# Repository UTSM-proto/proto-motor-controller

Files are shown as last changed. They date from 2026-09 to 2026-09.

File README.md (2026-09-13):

# UTSM motor controller

RP2040 Pico firmware and StinkyController KiCad hardware.

On Windows, double-click **Launch Programmer.cmd** to edit the firmware configuration and build/program a connected Pico. The editor includes 40 settings plus the manual hall table, descriptions, sliders, numeric inputs, voltage conversion, profile import/export and a build log.

See [programmer setup and operation](programmer/README.md) for dependencies, firmware changes and testing. See [hardware files](hardware/StinkyController/README.md) for PCB revisions and manufacturing outputs. `blink.c` is the active firmware target; `temp.c` is a legacy copy and is not built.

The GUI generates an isolated configuration header for each build. The checked-in firmware defaults are in `firmware/controller_config.h`; `programmer/config.py` defines the editor schema and validation. Keep both synchronized when changing defaults.

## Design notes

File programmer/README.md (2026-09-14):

# Windows Pico programmer

Double-click **Launch Programmer.cmd** in the repository root. Python starts a local service and opens the configuration page in your browser. Keep its terminal open while using the app. Python 3.10+ is required; the app itself has no pip dependencies.

1. Adjust settings using number fields, sliders or On/Off menus. Throttle thresholds also accept external volts; the default 5 V display scale corresponds to 4095 ADC counts, not permission to apply 5 V to a Pico pin.
2. Save/import JSON profiles to keep configurations. Defaults match the last 1.25 V throttle setting, with synchronous switching off. The sensor scale factors now retain the fractional part that the old integer constants discarded.
3. Connect a Pico normally by USB. Detection updates automatically every ten seconds; **Refresh devices** also checks immediately. Select the Pico if more than one is connected.
4. **Build UF2 only** compiles without touching hardware. **Build & program Pico** builds a snapshot, requests a software USB reboot, follows the selected physical USB port into the bootloader, and transfers the UF2 through Windows' standard USB drive interface. It then waits for the application to return on that port and report the expected build ID. No manual BOOTSEL step or RP2 Boot WinUSB driver is required in normal operation. Automatic identification moves the motor on restart. Release throttle before operation.
5. Close other serial monitors before programming. Software reboot requires responsive firmware with Pico SDK USB reset support. If firmware hangs or USB is disabled, manual BOOTSEL remains the recovery method. Devices using nonstandard USB IDs are not currently enumerated. Only the original RP2040 Pico is supported by this build target.

The application and bootloader may have different serial numbers. The programmer correlates their physical USB location and resolves the bootloader volume through Windows device ancestry, never just by drive letter or volume label. Completion requires the expected firmware build ID over USB after transfer; this is startup confirmation, not byte-for-byte flash readback or validation of motor behavior. The [Pico SDK USB reset mechanism](https://github.com/raspberrypi/pico-sdk/blob/2.1.0/src/rp2_common/pico_stdio_usb/reset_interface.c) uses a 1200-baud serial request. Picotool remains a build dependency for producing UF2 files, but is not used to upload them.

Every build lives in `.programmer/builds/<id>/`, with `config.json`, the source snapshot, `controller.uf2`, `manifest.json` (including SHA-256), and `operation.log`. Download UF2 from the page or use the saved file. Builds do not modify the checked-in default header. Changes made while a build runs belong to the next build.

Matching builds are reused automatically for both build-only and programming operations. The cache key covers the generated configuration, firmware sources, build recipe, executable checksums, SDK/toolchain file sizes and modification times, and relevant build environment. Each cache hit verifies the UF2 checksum and keeps the original firmware build ID for USB startup confirmation. Missing or damaged cache files cause a rebuild. Cache entries are saved after successful compilation even if the subsequent USB operation fails, so a programming retry does not compile again. Builds made before the cache was introduced require one new build to establish their cache entry. Each operation still gets its own log and manifest.

The launcher uses one dashboard on port 8766. Launching it again opens the existing instance; after an update it gracefully replaces an idle outdated instance. A running build/write cannot be interrupted this way. An old server also refuses new programming jobs if its backend files have changed, with a message to run the launcher again.

## Serial monitor and motor diagnosis

Select the connected Pico and use **Connect monitor**. The monitor reads USB at 115200 baud, shows raw timestamped lines and decoded calibration, drive-block, throttle ADC, hall, motor-state and duty/armed values. It can read the older CSV format too. Connecting does not reboot the Pico or send motor commands. **Clear display** clears the browser buffer; **Save visible log** exports it. Up to 1500 lines are retained for display, and each connection saves up to 10 MB under `.programmer/serial/`.

If the monitor is connected when programming begins, the programmer closes its serial handle before USB reset and reconnects after successful firmware confirmation. Disconnect any external serial monitor to avoid port conflicts. A failed upload may leave this monitor paused; reconnect it when the device is back in normal USB mode.

Firmware diagnostics persist after startup: `cal` reports success or the calibration failure type, `cal_sector` identifies the failed sector, and `cal_observed` lists the six sampled hall codes (255 means unavailable/rejected). `raw_hall` is the last simultaneous GPIO snapshot; binary digits are Hall C, B, A. `hall` is the majority-filtered code. `block` explains why drive is disabled. `throttle_not_released` means the throttle has not gone below the start threshold since boot; `calibration_failed` means PWM control was never enabled. These diagnostic additions do not alter calibration passes or relax validation.

Start diagnosis with the persistent calibration result. If calibration failed, inspect the recorded sector/codes before changing duty, settling time or pass count. If calibration passed, inspect throttle ADC/arming, then hall transition counters and commanded duty. Firmware startup confirmation during upload does not imply calibration passed or motor drive is ready.

Brief ambiguous Hall reads now blank the outputs without resetting the throttle ramp. The `invalid` counter includes whole-state vote ties, not only physical 000/111 inputs. `duty` reports the retained internal command; outputs are off whenever `block=invalid_hall` or `hall_settling`. The current integrator is frozen while blanked. If no stable sector is accepted for `HALL_LOSS_TIMEOUT_CYCLES` (default 16, approximately 1 ms at 16 kHz), `block=hall_loss_fault` latches drive off and resets the ramp until throttle release. Skipped-sector and ADC shutdowns remain in place. The timeout must exceed runtime stable cycles. This recovery timing still needs physical bench acceptance.

Profiles saved before the Hall loss timeout setting was added must be recreated using the current editor; older schemas are rejected explicitly. Reload the dashboard using the launcher after updating the backend.

## Build tools

The page reports detected tool paths. It supports the Pico VS Code tool layout, the existing UTSM tools directory, STM32Cube Arm GCC/Ninja, or explicit environment variables:

| Variable | Value |
| --- | --- |
| `PICO_SDK_PATH` | Pico SDK 2.1.0 directory, including the TinyUSB submodule |
| `UTSM_CMAKE` | Full path to `cmake.exe` |
| `UTSM_NINJA` | Full path to `ninja.exe` |
| `UTSM_ARM_GCC` | Full path to `arm-none-eabi-gcc.exe` |
| `UTSM_PICOTOOL` | Full path to `picotool.exe`; keep its CMake package files alongside it |

Install Python, Git, CMake, Ninja, the Arm GNU embedded toolchain and [picotool](https://github.com/raspberrypi/picotool/releases). The tested laptop uses SDK 2.1.0, Arm GCC 14.3.1 and picotool 2.3.1. To install the SDK into the auto-detected directory from PowerShell:

```powershell
git clone --depth 1 --branch 2.1.0 https://github.com/raspberrypi/pico-sdk.git "$env:LOCALAPPDATA\UTSM\PicoTools\pico-sdk-2.1.0"
git -C "$env:LOCALAPPDATA\UTSM\PicoTools\pico-sdk-2.1.0" submodule update --init --depth 1 lib/tinyusb
```

Do not run the clone command over an existing SDK checkout. Restart the programmer after changing environment variables. On another laptop, missing tools block the build with an actionable error; the app does not silently install software.

## Firmware fixes in this branch

- Startup hall identification runs once. It gathers consecutive stable whole-state readings, rejects invalid/duplicate states, and publishes a table only after all six sectors pass. Failed identification or a bad manual table keeps the drive disabled.
- Hall inputs use one GPIO register snapshot per sample and vote on complete three-bit codes. Temporal filtering spans PWM cycles. Uncertain states blank the phases; normal settling does not reset the throttle ramp. Skipped-sector faults clear when throttle is released, allowing resynchronization without reboot.
- Three ordered blocking ADC conversions replace the FIFO race. They read explicitly selected current, bus-voltage and throttle channels. ADC errors turn drive off and require throttle release. The control-loop timing must still be measured on hardware, especially with current control enabled.
- PWM outputs receive their off levels after initialization and before the GPIO function is switched. This avoids initialization clearing the off compare value on inverted low-side outputs.
- Current control handles zero duty without division by zero, uses a wide intermediate for current-limit arithmetic, and cannot integrate positive duty at zero throttle.
- Synchronous switching is one explicit setting, off by default in both control modes. The GUI validates pin uniqueness, paired PWM channels, separate slices, ADC pins, throttle ordering and manual tables.
- Telemetry snapshots shared values before printing: `current_mA,target_mA,duty16,bus_mV,hall,motor_state,invalid=N,transitions=N,adc=N`. Each interval also prints `build=<id>` for programming confirmation. A hall value of 255 means the sampled state was rejected. Calibration/table failures print a fault repeatedly.

The PCB's 5 V hall pull-ups remain a hardware issue. These firmware fixes cannot level-shift the hall inputs. Inspect the interface before powered tests. Calibration can still fail if duty is too low to move the rotor; it will now report failure and disable drive instead of accepting an incomplete table.

## Verification and bench acceptance

```powershell
python -m unittest discover -s tests -v
gcc -std=c11 -Wall -Wextra -Werror tests\test_logic.c -o .programmer\test_logic.exe
.\.programmer\test_logic.exe
```

`gcc` in this test command is a Windows host compiler, not Arm GCC. Create `.programmer` first if the app has never run. `tests/browser_smoke.cjs` additionally exercises the actual page and build using Playwright; set `PROGRAMMER_URL` to the authenticated URL printed by the service.

Before accepting motor operation, verify the gate outputs and ISR timing with a scope, confirm hall pin voltages, capture a complete calibration table, and check slow forward/reverse hand rotation with the power stage disabled. Then test controlled low-power startup, zero-throttle shutoff and hall-fault recovery. A successful build or USB verification does not establish correct motor commutation.

The service listens only on 127.0.0.1 and uses a random session token plus host/origin checks. There is no remote control endpoint, shell input, or automatic flash on page load.

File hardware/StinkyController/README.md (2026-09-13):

# StinkyController hardware

This directory contains the KiCad PCB projects and manufacturing outputs from
the supplied `StinkyController 0.5.zip` archive.

## Project revisions

- `StinkyController 0.5`
- `StinkyController 1`
- `StinkyController 1.1`
- `StinkyController MK2` (newest PCB and Gerber revision in the archive)

The `gerb*` directories and ZIP files contain the supplied manufacturing
outputs. Generated KiCad user preferences, caches, backups, and macOS metadata
are excluded from version control.

## Missing source

The supplied archive does not contain a `.kicad_sch` schematic file. The PCB
files retain component values, footprints, net names, and routed connectivity,
but the editable schematic source will need to be added separately if it still
exists.

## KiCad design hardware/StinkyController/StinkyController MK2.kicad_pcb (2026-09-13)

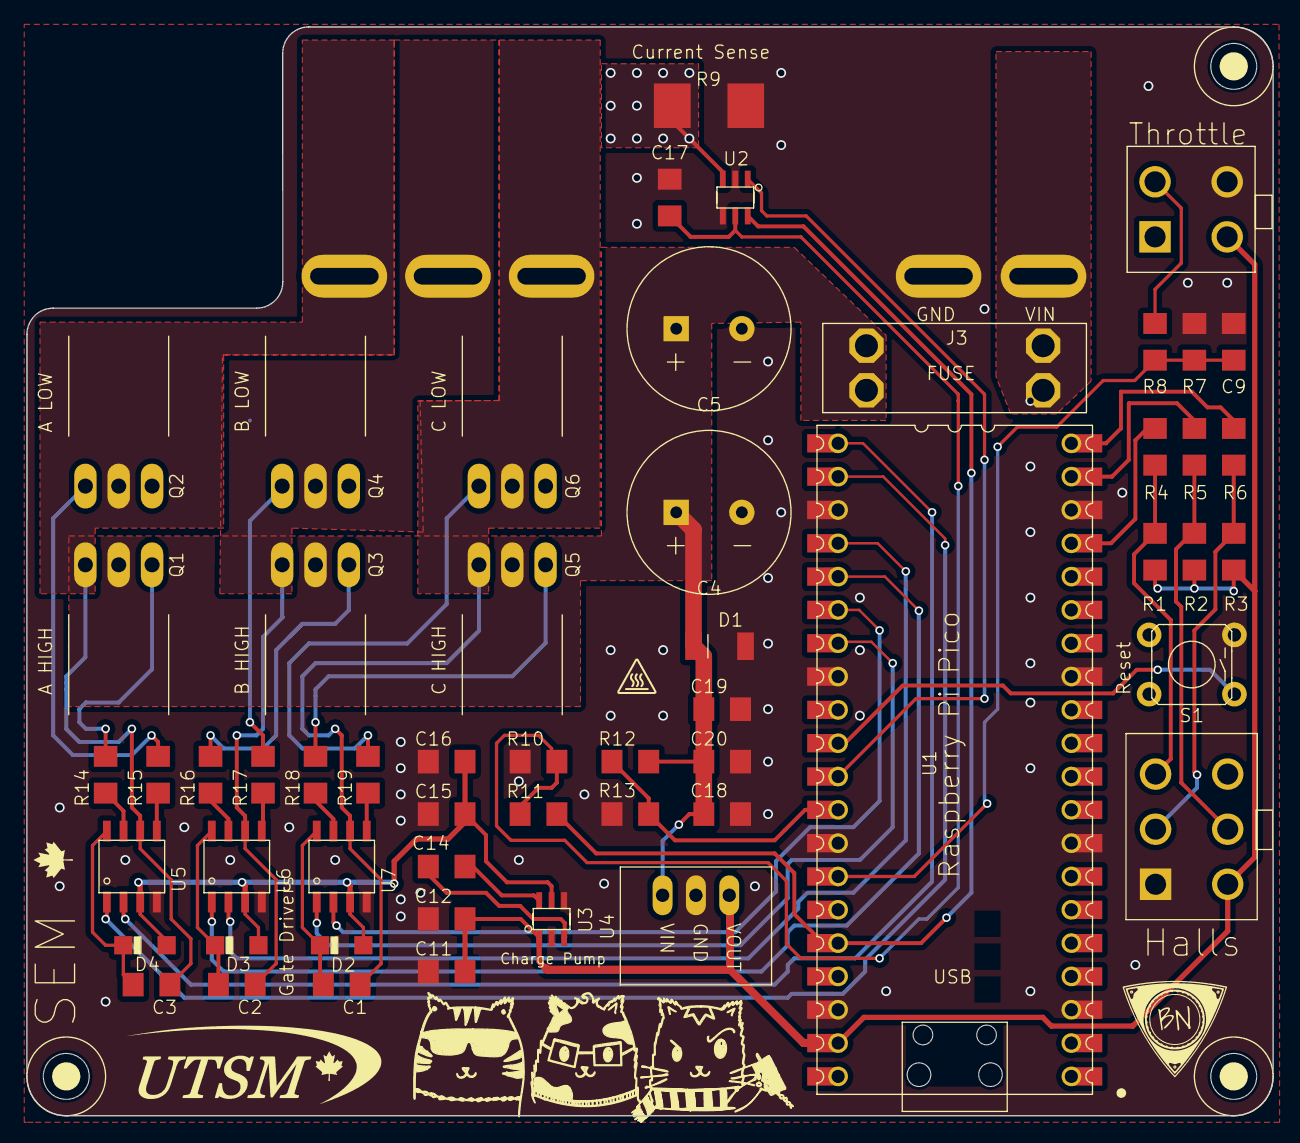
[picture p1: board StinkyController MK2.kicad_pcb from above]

Board: 2 copper layers, 95.0 x 83.0 mm, 58 parts (0 on the bottom side), 46 nets.

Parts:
C1, C2, C3, C11, C12, C14, C15, C16, C17, C18, C19, C20: 1uF; 1206
C4, C5: 470uF; CPOL-RADIAL-5MM-10MM
C9: 22nF; 1206
D1: TVS; DO-214AC
D2, D3, D4: SOD-123
J1: HEADER4VALULOK; 4PINVALULOK
J2: HEADER6; 6PINVALULOK
J3: FUSE; AUTO_FUSE
Q1, Q2, Q3, Q4, Q5, Q6: TO-220-FLAT
R1, R2, R3, R4, R5, R6, R13: 2.2k; 1206
R7, R8, R10, R11, R12: 47k; 1206
R9: 0.0005; R2512
R14, R15, R16, R17, R18, R19: 22; 1206
S1: TACTILE_SWITCH_PTH_6.0MM
U1: PICO-PKG-NO_DEBUG
U2: INA181; SOT23-6
U3: TC1240A; SOT23-6
U4: K78U05; V78W_BACKWARDS
U5, U6, U7: DGD2304; SOIC8
U$10, U$11, U$12: SCREW; M3HOLE

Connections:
3.3V: R11.2, U1.36, U1.P$36, U2.6
5V: C11.1, C12.1, J1.2, J2.2, R1.2, R2.2, R3.2, U1.39, U1.P$39, U3.1, U4.OUT
10V: C15.1, C16.1, D2.+, D3.+, D4.+, U3.5, U5.3, U6.3, U7.3
COM_A: C3.2, Q1.3, Q2.2, U5.6
COM_B: C2.2, Q3.3, Q4.2, U6.6
COM_C: C1.2, Q5.3, Q6.2, U7.6
CTRL_AH: U1.21, U1.P$21, U5.2
CTRL_AL: U1.22, U1.P$22, U5.1
CTRL_BH: U1.24, U1.P$24, U6.2
CTRL_BL: U1.25, U1.P$25, U6.1
CTRL_CH: U1.26, U1.P$26, U7.2
CTRL_CL: U1.27, U1.P$27, U7.1
DRV_AH: R14.1, U5.7
DRV_AL: R15.1, U5.5
DRV_BH: R16.1, U6.7
DRV_BL: R17.1, U6.5
DRV_CH: R18.1, U7.7
DRV_CL: R19.1, U7.5
GND: C4.-, C5.-, C9.2, C11.2, C12.2, C15.2, C16.2, C17.2, C18.2, C19.2, C20.2, D1.A, J1.4, J2.1, R7.1, R9.1, R10.1, R13.1, S1.3, U1.3, U1.8, U1.13, U1.18, U1.23, U1.28, U1.33, U1.38, U1.P$3, U1.P$8, U1.P$13, U1.P$18, U1.P$23, U1.P$28, U1.P$33, U1.P$38, U2.2, U2.4, U3.2, U3.4, U4.GND, U5.4, U6.4, U7.4
HALL_A: R4.2, U1.17, U1.P$17
HALL_B: R5.2, U1.19, U1.P$19
HALL_C: R6.2, U1.20, U1.P$20
ISENSE: U1.31, U1.P$31, U2.1
unnamed: C2.1, D3.-, U6.8
unnamed: J2.3, R3.1, R6.1
unnamed: C3.1, D4.-, U5.8
unnamed: J2.4, R2.1, R5.1
unnamed: Q1.1, R14.2
unnamed: J2.5, R1.1, R4.1
unnamed: J1.3, R8.1
unnamed: C1.1, D2.-, U7.8
unnamed: S1.1, U1.30, U1.P$30
unnamed: C17.1, R10.2, R11.1, U2.5
unnamed: Q2.1, R15.2
unnamed: Q3.1, R16.2
unnamed: Q4.1, R17.2
unnamed: Q5.1, R18.2
unnamed: Q6.1, R19.2
unnamed: C14.1, U3.3
unnamed: C14.2, U3.6
SHUNT+: Q2.3, Q4.3, Q6.3, R9.2, U2.3
THROTTLE: C9.1, R7.2, R8.2, U1.34, U1.P$34
VBUS: U1.40, U1.P$40
VSENSE: R12.1, R13.2, U1.32, U1.P$32
V_PREFUSE: J3.1A, J3.1B
V_RAW: C4.+, C5.+, C18.1, C19.1, C20.1, D1.C, J3.2A, J3.2B, Q1.2, Q3.2, Q5.2, R12.2, U4.IN

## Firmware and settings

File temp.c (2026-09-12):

#include <stdio.h>

#include "hardware/adc.h"
#include "hardware/clocks.h"
#include "hardware/gpio.h"
#include "hardware/irq.h"
#include "hardware/pwm.h"
#include "hardware/sync.h"
#include "hardware/uart.h"
#include "pico/stdlib.h"

///////

/**
 * Copyright (c) 2020 Raspberry Pi (Trading) Ltd.
 *
 * SPDX-License-Identifier: BSD-3-Clause
 */

#include "pico/stdlib.h"
// Pico W devices use a GPIO on the WIFI chip for the LED,
// so when building for Pico W, CYW43_WL_GPIO_LED_PIN will be defined
#ifdef CYW43_WL_GPIO_LED_PIN
#include "pico/cyw43_arch.h"
#endif

#ifndef LED_DELAY_MS
#define LED_DELAY_MS 100
#endif

// Perform initialisation
int pico_led_init(void) {
#if defined(PICO_DEFAULT_LED_PIN)
  // A device like Pico that uses a GPIO for the LED will define
  // PICO_DEFAULT_LED_PIN so we can use normal GPIO functionality to turn the
  // led on and off
  gpio_init(PICO_DEFAULT_LED_PIN);
  gpio_set_dir(PICO_DEFAULT_LED_PIN, GPIO_OUT);
  return PICO_OK;
#elif defined(CYW43_WL_GPIO_LED_PIN)
  // For Pico W devices we need to initialise the driver etc
  return cyw43_arch_init();
#endif
}

// Turn the led on or off
void pico_set_led(bool led_on) {
#if defined(PICO_DEFAULT_LED_PIN)
  // Just set the GPIO on or off
  gpio_put(PICO_DEFAULT_LED_PIN, led_on);
#elif defined(CYW43_WL_GPIO_LED_PIN)
  // Ask the wifi "driver" to set the GPIO on or off
  cyw43_arch_gpio_put(CYW43_WL_GPIO_LED_PIN, led_on);
#endif
}
///////

// Begin user config section ---------------------------

const int THROTTLE_LOW =
    600;  // ADC value corresponding to minimum throttle, 0-4095
const int THROTTLE_HIGH =
    2650;  // ADC value corresponding to maximum throttle, 0-4095

const bool CURRENT_CONTROL =
    false;  // Use current control or duty cycle control
const int PHASE_MAX_CURRENT_MA =
    6000;  // If using current control, the maximum phase current allowed
const int BATTERY_MAX_CURRENT_MA =
    3000;  // If using current control, the maximum battery current allowed
const int CURRENT_CONTROL_LOOP_GAIN =
    200;  // Adjusts the speed of the current control loop

const uint ABC[] = {0, 1, 2, 3, 4, 5};
const uint ACB[] = {1, 0, 5, 4, 3, 2};
const uint BAC[] = {3, 2, 1, 0, 5, 4};
const uint BCA[] = {2, 3, 4, 5, 0, 1};
const uint CAB[] = {4, 5, 0, 1, 2, 3};
const uint CBA[] = {5, 4, 3, 2, 1, 0};

const uint *PHASE_WIRING_ORDER = CBA;

// Comutation Orders

// ABC              ACB             BAC             BCA             CAB CBA A
// LOW, B HIGH    A LOW, C HIGH   B LOW, A HIGH   B LOW, C HIGH   C LOW, A HIGH
// C LOW, B HIGH A LOW, C HIGH    A LOW, B HIGH   B LOW, C HIGH   B LOW, A HIGH
// C LOW, B HIGH   C LOW, A HIGH B LOW, C HIGH    C LOW, B HIGH   A LOW, C HIGH
// C LOW, A HIGH   A LOW, B HIGH   B LOW, A HIGH B LOW, A HIGH    C LOW, A HIGH
// A LOW, B HIGH   C LOW, B HIGH   A LOW, C HIGH   B LOW, C HIGH C LOW, A HIGH
// B LOW, A HIGH   C LOW, B HIGH   A LOW, B HIGH   B LOW, C HIGH   A LOW, C HIGH
// C LOW, B HIGH    B LOW, C HIGH   C LOW, A HIGH   A LOW, C HIGH   B LOW, A
// HIGH   A LOW, B HIGH

// End user config section -----------------------------

const uint LED_PIN = 25;

const uint AH_PIN = 16;
const uint AL_PIN = 17;
const uint BH_PIN = 18;
const uint BL_PIN = 19;
const uint CH_PIN = 20;
const uint CL_PIN = 21;

// Optical Encoder Pin Definitions
// Encoder 1
const uint OPT_U1_PIN = 10;
const uint OPT_V1_PIN = 11;
const uint OPT_W1_PIN = 12;

// Encoder 2
const uint OPT_U2_PIN = 13;
const uint OPT_V2_PIN = 14;
const uint OPT_W2_PIN = 15;

const uint ISENSE_PIN = 26;
const uint VSENSE_PIN = 27;
const uint THROTTLE_PIN = 28;

const uint A_PWM_SLICE = 0;
const uint B_PWM_SLICE = 1;
const uint C_PWM_SLICE = 2;

const uint F_PWM = 16000;  // Desired PWM frequency
const uint FLAG_PIN = 2;

const int DUTY_CYCLE_MAX = 65535;
const int CURRENT_SCALING = 3.3 / 0.0005 / 20 / 4096 * 1000;
const int VOLTAGE_SCALING = 3.3 / 4096 * (47 + 2.2) / 2.2 * 1000;
const int ADC_BIAS_OVERSAMPLE = 1000;

int adc_isense = 0;
int adc_vsense = 0;
int adc_throttle = 0;

int adc_bias = 0;
int duty_cycle = 0;
int voltage_mv = 0;
int current_ma = 0;
int current_target_ma = 0;
int optical = 0;
uint motorState = 0;
int fifo_level = 0;
uint64_t ticks_since_init = 0;

uint get_opti();
void writePWM(uint motorState, uint duty, bool synchronous);
uint8_t read_throttle();

void on_adc_fifo() {
  // This interrupt is where the magic happens. This is fired once the ADC
  // conversions have finished (roughly 6us for 3 conversions) This reads the
  // optical sensors, determines the motor state to switch to, and reads the
  // current sensors and throttle to determine the desired duty cycle. This
  // takes ~7us to complete.

  uint32_t flags =
      save_and_disable_interrupts();  // Disable interrupts for the
                                      // time-critical reading ADC section. USB
                                      // interrupts may interfere

  adc_run(false);         // Stop the ADC from free running
  gpio_put(FLAG_PIN, 1);  // For debugging, toggle the flag pin

  fifo_level = adc_fifo_get_level();
  adc_isense = adc_fifo_get();  // Read the ADC values into the registers
  adc_vsense = adc_fifo_get();

  adc_throttle = 1000;  // temp value
  // adc_throttle = adc_fifo_get();

  restore_interrupts(flags);  // Re-enable interrupts

  if (fifo_level != 3) {
    // The RP2040 is a shitty microcontroller. The ADC is unpredictable, and 1%
    // of times will return more or less than the 3 samples it should. If we
    // don't get the expected number, abort
    return;
  }

  optical = get_opti();  // Read the optical sensors
  motorState = optical - 1;

  int throttle = ((adc_throttle - THROTTLE_LOW) * 256) /
                 (THROTTLE_HIGH -
                  THROTTLE_LOW);  // Scale the throttle value read from the ADC
  throttle = MAX(0, MIN(255, throttle));  // Clamp to 0-255

  current_ma = (adc_isense - adc_bias) *
               CURRENT_SCALING;  // Since the current sensor is bidirectional,
                                 // subtract the zero-current value and scale
  voltage_mv = adc_vsense * VOLTAGE_SCALING;  // Calculate the bus voltage

  if (CURRENT_CONTROL) {
    int user_current_target_ma =
        throttle * PHASE_MAX_CURRENT_MA /
        256;  // Calculate the user-demanded phase current
    int battery_current_limit_ma =
        BATTERY_MAX_CURRENT_MA * DUTY_CYCLE_MAX /
        duty_cycle;  // Calculate the maximum phase current allowed while
                     // respecting the battery current limit
    current_target_ma = MIN(user_current_target_ma, battery_current_limit_ma);

    if (throttle == 0) {
      duty_cycle = 0;  // If zero throttle, ignore the current control loop and
                       // turn all transistors off
      ticks_since_init =
          0;  // Reset the timer since the transistors were turned on
    } else
      ticks_since_init++;

    duty_cycle +=
        (current_target_ma - current_ma) /
        CURRENT_CONTROL_LOOP_GAIN;  // Perform a simple integral controller to
                                    // adjust the duty cycle
    duty_cycle =
        MAX(0, MIN(DUTY_CYCLE_MAX, duty_cycle));  // Clamp the duty cycle

    bool do_synchronous =
        ticks_since_init >
        16000;  // Only enable synchronous switching some time after beginning
                // control loop. This allows control loop to stabilize
    writePWM(motorState, (uint)(duty_cycle / 256), do_synchronous);
  } else {
    duty_cycle = throttle * 256;  // Set duty cycle based directly on throttle
    bool do_synchronous =
        true;  // Note, if doing synchronous duty-cycle control, the motor will
               // regen if the throttle decreases. This may regen VERY HARD

    writePWM(motorState, (uint)(duty_cycle / 256), do_synchronous);
  }

  gpio_put(FLAG_PIN, 0);
}

void on_pwm_wrap() {
  // This interrupt is triggered when the A_PWM slice reaches 0 (the middle of
  // the PWM cycle) This allows us to start ADC conversions while the high-side
  // FETs are on, which is required to read current, based on where the current
  // sensor is placed in the schematic. Takes ~1.3 microseconds

  gpio_put(FLAG_PIN, 1);        // Toggle the flag pin high for debugging
  adc_select_input(0);          // Force the ADC to start with input 0
  adc_run(true);                // Start the ADC
  pwm_clear_irq(A_PWM_SLICE);   // Clear this interrupt flag
  while (!adc_fifo_is_empty())  // Clear out the ADC fifo, in case it still has
                                // samples in it
    adc_fifo_get();

  gpio_put(FLAG_PIN, 0);
}

void writePhases(uint ah, uint bh, uint ch, uint al, uint bl, uint cl) {
  // Set the timer registers for each PWM slice. The lowside values are
  // inverted, since the PWM slices were already configured to invert the
  // lowside pin. ah: desired high-side duty cycle, range of 0-255 al: desired
  // low-side duty cycle, range of 0-255

  pwm_set_both_levels(A_PWM_SLICE, ah, 255 - al);
  pwm_set_both_levels(B_PWM_SLICE, bh, 255 - bl);
  pwm_set_both_levels(C_PWM_SLICE, ch, 255 - cl);
}

void writePWM(uint motorState, uint duty, bool synchronous) {
  // Switch the transistors given a desired electrical state and duty cycle
  // motorState: desired electrical position, range of 0-5
  // duty: desired duty cycle, range of 0-255
  // synchronous: perfom synchronous (low-side and high-side alternating) or
  // non-synchronous switching (high-side only)

  if (duty == 0 ||
      duty > 255)  // If zero throttle, turn both low-sides and high-sides off
    motorState = 255;

  // At near 100% duty cycles, the gate driver bootstrap capacitor may become
  // discharged as the high-side gate is repeatedly driven high and low without
  // time for the phase voltage to fall to zero and charge the bootstrap
  // capacitor. Thus, if duty cycle is near 100%, clamp it to 100%.
  if (duty > 245) duty = 255;

  uint complement = 0;
  if (synchronous) {
    complement = MAX(0, 248 - (int)duty);  // Provide switching deadtime by
                                           // having duty + complement < 255
  }
  writePhases(duty, duty, duty, 0, 0, 0);
  // if(motorState == PHASE_WIRING_ORDER[0])                         // LOW A,
  // HIGH B
  //     writePhases(0, duty, 0, 255, complement, 0);
  // else if(motorState == PHASE_WIRING_ORDER[1])                    // LOW A,
  // HIGH C
  //     writePhases(0, 0, duty, 255, 0, complement);
  // else if(motorState == PHASE_WIRING_ORDER[2])                    // LOW B,
  // HIGH C
  //     writePhases(0, 0, duty, 0, 255, complement);
  // else if(motorState == PHASE_WIRING_ORDER[3])                    // LOW B,
  // HIGH A
  //     writePhases(duty, 0, 0, complement, 255, 0);
  // else if(motorState == PHASE_WIRING_ORDER[4])                    // LOW C,
  // HIGH A
  //     writePhases(duty, 0, 0, complement, 0, 255);
  // else if(motorState == PHASE_WIRING_ORDER[5])                    // LOW C,
  // HIGH B
  //     writePhases(0, duty, 0, 0, complement, 255);
  // else                                        // All transistors off
  //     writePhases(0, 0, 0, 0, 0, 0);
}

void init_hardware() {
  // Initialize all peripherals

  stdio_init_all();

  gpio_init(LED_PIN);  // Set LED and FLAG pin as outputs
  gpio_set_dir(LED_PIN, GPIO_OUT);
  gpio_init(FLAG_PIN);
  gpio_set_dir(FLAG_PIN, GPIO_OUT);

  gpio_init(OPT_U1_PIN);  // Set up optical sensor pins
  gpio_set_dir(OPT_U1_PIN, GPIO_IN);
  gpio_init(OPT_V1_PIN);
  gpio_set_dir(OPT_V1_PIN, GPIO_IN);
  gpio_init(OPT_W1_PIN);
  gpio_set_dir(OPT_W1_PIN, GPIO_IN);

  gpio_init(OPT_U2_PIN);  // Set up optical sensor pins
  gpio_set_dir(OPT_U2_PIN, GPIO_IN);
  gpio_init(OPT_V2_PIN);
  gpio_set_dir(OPT_V2_PIN, GPIO_IN);
  gpio_init(OPT_W2_PIN);
  gpio_set_dir(OPT_W2_PIN, GPIO_IN);

  gpio_set_function(AH_PIN, GPIO_FUNC_PWM);  // Set gate control pins as output
  gpio_set_function(AL_PIN, GPIO_FUNC_PWM);
  gpio_set_function(BH_PIN, GPIO_FUNC_PWM);
  gpio_set_function(BL_PIN, GPIO_FUNC_PWM);
  gpio_set_function(CH_PIN, GPIO_FUNC_PWM);
  gpio_set_function(CL_PIN, GPIO_FUNC_PWM);

  adc_init();
  adc_gpio_init(ISENSE_PIN);  // Set up ADC pins
  adc_gpio_init(VSENSE_PIN);
  adc_gpio_init(THROTTLE_PIN);

  sleep_ms(100);
  for (uint i = 0; i < ADC_BIAS_OVERSAMPLE;
       i++)  // Find the zero-current ADC reading. Reads the ADC multiple times
             // and takes the average
  {
    adc_select_input(0);
    adc_bias += adc_read();
  }
  adc_bias /= ADC_BIAS_OVERSAMPLE;

  adc_set_round_robin(0b111);  // Set ADC to read our three ADC pins one after
                               // the other (round robin)
  adc_fifo_setup(true, false, 3, false,
                 false);  // ADC writes into a FIFO buffer, and an interrupt is
                          // fired once FIFO reaches 3 samples
  irq_set_exclusive_handler(ADC_IRQ_FIFO, on_adc_fifo);  // Sets ADC interrupt
  irq_set_priority(ADC_IRQ_FIFO, 0);
  adc_irq_set_enabled(true);
  irq_set_enabled(ADC_IRQ_FIFO, true);

  pwm_clear_irq(A_PWM_SLICE);  // Clear interrupt flag, just in case
  irq_set_exclusive_handler(
      PWM_IRQ_WRAP,
      on_pwm_wrap);  // Set interrupt to fire when PWM counter wraps
  irq_set_priority(PWM_IRQ_WRAP, 0);
  irq_set_enabled(PWM_IRQ_WRAP, true);

  float pwm_divider = (float)(clock_get_hz(clk_sys)) /
                      (F_PWM * 255 * 2);  // Calculate the desired PWM divisor
  pwm_config config = pwm_get_default_config();
  pwm_config_set_clkdiv(&config, pwm_divider);
  pwm_config_set_wrap(&config,
                      255 - 1);  // Set the PWM to wrap at 254. This allows a
                                 // PWM value of 255 to equal 100% duty cycle
  pwm_config_set_phase_correct(
      &config,
      true);  // Set phase correct (counts up then down). This is allows firing
              // the interrupt in the middle of the PWM cycle
  pwm_config_set_output_polarity(
      &config, false, true);  // Invert the lowside PWM such that 0 corresponds
                              // to lowside transistors on

  writePhases(0, 0, 0, 0, 0, 0);  // Initialize all the PWMs to be off

  pwm_init(A_PWM_SLICE, &config, false);
  pwm_init(B_PWM_SLICE, &config, false);
  pwm_init(C_PWM_SLICE, &config, false);

  pwm_set_mask_enabled(0x07);  // Enable our three PWM timers
}

uint get_opti() {
  uint state_OPT_1 = gpio_get(OPT_U1_PIN) * 4 + gpio_get(OPT_V1_PIN) * 2 +
                     gpio_get(OPT_W1_PIN) * 1;

  uint state_OPT_2 = gpio_get(OPT_U2_PIN) * 4 + gpio_get(OPT_V2_PIN) * 2 +
                     gpio_get(OPT_W2_PIN) * 1;

  // Combine state_OPT_1 and state_OPT_2 into a single value
  uint combined_state = (state_OPT_1 << 3) | state_OPT_2;

  // ABC              ACB             BAC             BCA             CAB CBA
  // A LOW, B HIGH    A LOW, C HIGH   B LOW, A HIGH   B LOW, C HIGH   C LOW, A
  // HIGH   C LOW, B HIGH A LOW, C HIGH    A LOW, B HIGH   B LOW, C HIGH   B
  // LOW, A HIGH   C LOW, B HIGH   C LOW, A HIGH B LOW, C HIGH    C LOW, B HIGH
  // A LOW, C HIGH   C LOW, A HIGH   A LOW, B HIGH   B LOW, A HIGH B LOW, A HIGH
  // C LOW, A HIGH   A LOW, B HIGH   C LOW, B HIGH   A LOW, C HIGH   B LOW, C
  // HIGH C LOW, A HIGH    B LOW, A HIGH   C LOW, B HIGH   A LOW, B HIGH   B
  // LOW, C HIGH   A LOW, C HIGH C LOW, B HIGH    B LOW, C HIGH   C LOW, A HIGH
  // A LOW, C HIGH   B LOW, A HIGH   A LOW, B HIGH

  switch (combined_state) {  // uvw uvw
    case 41:
      return 1;  // 0b101 001
    case 33:
      return 2;  // 0b100 001
    case 37:
      return 3;  // 0b100 101
    case 53:
      return 4;  // 0b110 101
    case 52:
      return 5;  // 0b110 100
    case 20:
      return 6;  // 0b010 100

    case 22:
      return 1;  // 0b010 110
    case 30:
      return 2;  // 0b011 110
    case 26:
      return 3;  // 0b011 010
    case 10:
      return 4;  // 0b001 010
    case 11:
      return 5;  // 0b001 011
    case 43:
      return 6;  // 0b101 011

    default:
      return 0;  // Invalid state
  }
}

void commutate_open_loop() {
  // A useful function to debug electrical problems with the board.
  // This slowly advances the motor commutation without reading optical sensors.
  // The motor should slowly spin
  int state = 0;
  while (true) {
    writePWM(state % 6, 25, false);
    sleep_ms(50);
    state++;
  }
}

int main() {
  init_hardware();

  int rc = pico_led_init();
  hard_assert(rc == PICO_OK);

  sleep_ms(1000);

  pwm_set_irq_enabled(A_PWM_SLICE,
                      true);  // Enables interrupts, starting motor commutation

  while (true) {
    printf("%6d, %6d, %6d, %6d, %2d, %2d\n", current_ma, current_target_ma,
           duty_cycle, voltage_mv, optical, motorState);
    gpio_put(LED_PIN, !gpio_get(LED_PIN));  // Toggle the LED
    sleep_ms(100);
  }

  return 0;
}

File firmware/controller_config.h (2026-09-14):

// Generated configuration. Edit with the Windows programmer.
#pragma once
#define THROTTLE_LOW (540)
#define THROTTLE_HIGH (3300)
#define THROTTLE_INPUT_FULL_SCALE_V (5)
#define THROTTLE_SLEW_RATE (1)
#define CURRENT_CONTROL (0)
#define PHASE_MAX_CURRENT_MA (13000)
#define BATTERY_MAX_CURRENT_MA (13000)
#define CURRENT_CONTROL_LOOP_GAIN (700)
#define SYNCHRONOUS_SWITCHING (0)
#define SYNCHRONOUS_DELAY_CYCLES (16000)
#define IDENTIFY_HALLS_ON_BOOT (1)
#define IDENTIFY_HALLS_REVERSE (1)
#define HALL_IDENTIFY_DUTY_CYCLE (25)
#define HALL_IDENTIFY_SETTLE_MS (500)
#define HALL_IDENTIFY_STABLE_SAMPLES (20)
#define BOOT_DELAY_MS (2000)
#define HALL_OVERSAMPLE (8)
#define HALL_STABLE_CYCLES (2)
#define HALL_LOSS_TIMEOUT_CYCLES (16)
#define HALL_VALIDATE_TRANSITIONS (1)
#define CURRENT_SCALING (80.56640625)
#define VOLTAGE_SCALING (18.017578125)
#define ADC_BIAS_OVERSAMPLE (1000)
#define F_PWM (16000)
#define TELEMETRY_INTERVAL_MS (100)
#define PWM_FULL_ON_THRESHOLD (245)
#define PWM_COMPLEMENT_TOTAL (248)
#define LED_PIN (25)
#define FLAG_PIN (2)
#define AH_PIN (16)
#define AL_PIN (17)
#define BH_PIN (18)
#define BL_PIN (19)
#define CH_PIN (20)
#define CL_PIN (21)
#define HALL_1_PIN (13)
#define HALL_2_PIN (14)
#define HALL_3_PIN (15)
#define ISENSE_PIN (26)
#define VSENSE_PIN (27)
#define THROTTLE_PIN (28)
#define HALL_TABLE_INITIALIZER {255, 255, 255, 255, 255, 255, 255, 255}
#define DUTY_CYCLE_MAX 65535
// PWM slices and ADC channels are derived from GPIO assignments.

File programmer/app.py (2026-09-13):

"""Run with Python 3.10+ on Windows; opens a loopback-only browser GUI."""
import argparse
import hashlib
from http.server import BaseHTTPRequestHandler, ThreadingHTTPServer
import json
from pathlib import Path
import secrets
import threading
import time
from urllib.parse import urlparse
from urllib.request import Request, urlopen
from urllib.error import URLError
import webbrowser

from backend import Programmer, devices, toolchain
from config import FIELDS, defaults, validate
from serial_monitor import SerialMonitor


def service_signature():
    digest = hashlib.sha256()
    for name in ('app.py', 'backend.py', 'build_cache.py', 'config.py', 'usb_transport.py', 'windows_devices.ps1', 'serial_monitor.py', 'serial_reader.ps1'):
        digest.update((Path(__file__).parent / name).read_bytes())
    return digest.hexdigest()


LOADED_SIGNATURE = service_signature()


def existing_server(port):
    record = Path(__file__).resolve().parents[1] / '.programmer/server.json'
    try:
        url = json.loads(record.read_text())['url']
        parsed = urlparse(url)
        if parsed.scheme != 'http' or parsed.hostname != '127.0.0.1' or parsed.port != port:
            return None
        token = parsed.fragment.removeprefix('token=')
        base = f'http://127.0.0.1:{port}'
        headers = {'X-Programmer-Token': token}
        with urlopen(Request(base + '/api/server', headers=headers), timeout=3) as response:
            info = json.load(response)
    except (OSError, ValueError, KeyError, URLError):
        return None
    if info['version'] == LOADED_SIGNATURE:
        return url
    # Graceful shutdown is rejected while a build or USB write is active.
    with urlopen(Request(base + '/api/shutdown', data=b'{}', headers=headers), timeout=3):
        pass
    time.sleep(1)
    return None


def make_server(port=0):
    monitor = SerialMonitor(Path(__file__).resolve().parents[1] / '.programmer')
    programmer = Programmer(monitor)
    io_gate = threading.RLock()
    token = secrets.token_urlsafe(32)

    class Handler(BaseHTTPRequestHandler):
        def log_message(self, *_): pass

        def respond(self, code, data, kind="application/json"):
            body = json.dumps(data).encode() if kind == "application/json" else data
            self.send_response(code)
            self.send_header("Content-Type", kind)
            self.send_header("Content-Length", str(len(body)))
            self.send_header("Cache-Control", "no-store")
            self.send_header("X-Content-Type-Options", "nosniff")
            self.send_header("Content-Security-Policy", "default-src 'self'; script-src 'self'; style-src 'self'; frame-ancestors 'none'; base-uri 'none'; connect-src 'self'")
            self.end_headers()
            self.wfile.write(body)

        def authorized(self):
            expected = f"127.0.0.1:{self.server.server_port}"
            if self.headers.get("Host") != expected: return False
            origin = self.headers.get("Origin")
            if origin and origin != "http://" + expected: return False
            return secrets.compare_digest(self.headers.get("X-Programmer-Token", ""), token)

        def do_GET(self):
            path = urlparse(self.path).path
            if path in ("/", "/app.js", "/style.css"):
                if self.headers.get("Host") != f"127.0.0.1:{self.server.server_port}":
                    return self.respond(403, {"error": "Invalid host"})
                name = {"/": "index.html", "/app.js": "app.js", "/style.css": "style.css"}[path]
                kind = {"/": "text/html; charset=utf-8", "/app.js": "text/javascript; charset=utf-8", "/style.css": "text/css; charset=utf-8"}[path]
                return self.respond(200, (Path(__file__).parent / "web" / name).read_bytes(), kind)
            if not self.authorized(): return self.respond(403, {"error": "Reopen the app using Launch Programmer.cmd."})
            try:
                if path == "/api/config": return self.respond(200, dict(fields=FIELDS, defaults=defaults(), tools=toolchain()))
                if path == "/api/devices": return self.respond(200, devices())
                if path == "/api/job": return self.respond(200, programmer.status())
                if path == '/api/serial': return self.respond(200, monitor.snapshot())
                if path == "/api/server": return self.respond(200, dict(version=LOADED_SIGNATURE))
                if path == "/api/artifact":
                    job = programmer.status()
                    if not job or not job.get("artifact"): raise ValueError("No artifact available.")
                    return self.respond(200, Path(job["artifact"]).read_bytes(), "application/octet-stream")
                self.respond(404, {"error": "Not found"})
            except Exception as exc: self.respond(400, {"error": str(exc)})
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

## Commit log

2026-09-12 Initial motor controller firmware
2026-09-12 Lower throttle activation threshold to 1V
2026-09-12 Restore throttle activation threshold to 2.44V
2026-09-12 Set throttle activation threshold to 1.5V
2026-09-12 Set throttle activation threshold to 0.8V
2026-09-12 Set throttle activation threshold to 1.25V
2026-09-13 Add StinkyController KiCad hardware files
    [StinkyController 0.5-B_Cu.gbl, StinkyController 0.5-B_Mask.gbs, StinkyController 0.5-B_Paste.gbp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]
2026-09-13 Add Windows configuration programmer and fix hall startup and sampling
    [app.py, backend.py, blink.c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]
2026-09-13 Remove pinned throttle summary from programmer header
2026-09-13 Automate Windows Pico reboot and UF2 programming without boot driver
    [backend.py, blink.c, usb_transport.py]
2026-09-13 Reuse verified firmware builds and prevent stale dashboard uploads
    [app.py, backend.py, build_cache.py]
2026-09-13 Add live serial monitor and persistent motor calibration diagnostics
2026-09-14 Fix throttle surging on brief hall glitches
    [blink.c, config.py, controller_config.h]
